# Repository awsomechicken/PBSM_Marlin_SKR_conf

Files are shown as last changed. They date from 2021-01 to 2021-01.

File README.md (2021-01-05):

# PBSM_Marlin_SKR_conf
Configuration to upgrade the Printrbot Simple Metal to an SKR Mini V1.2 controller.

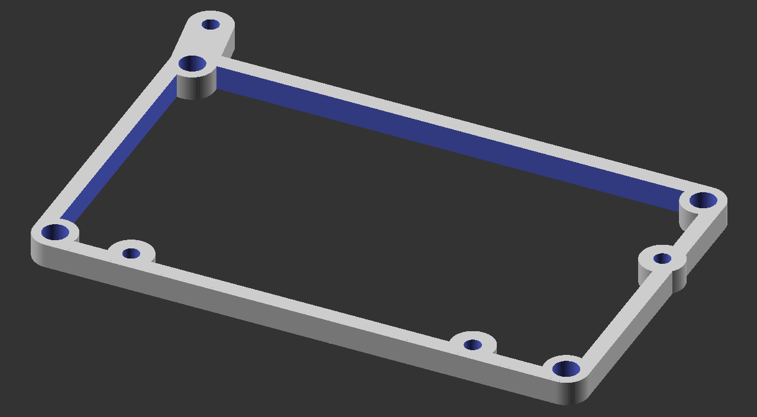
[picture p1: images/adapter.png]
Board mount

The board adapter (in its current form) needs 4x M3x5mm standoffs. to mount the board.

# Wiring:
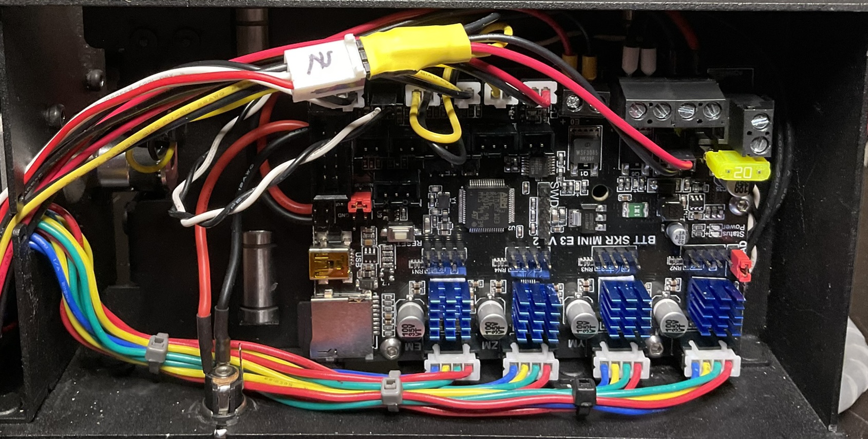
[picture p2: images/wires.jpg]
Wiring photo

#### Z-Probe voltage divider harness:
The inductive probe used for bed leveling, I've wired mine to run off the +12V tap on the board, with a 12k&Omega; voltage divider:

(Signal)----[9k&Omega;]----{Vout}----[3k&Omega;]----(GND)

Vout is the 3V signal from the signal output of the probe, wire this to the z-stop connector and __not__ the probe connector.

#### Motors:
I wired all the motors into JST connectors.

# Configuration Notes:
## Heaters:
#### Hotend:
PID settings for the Ubis hotend: `M301 P22.20 I1.08 D114.00`
#### Bed:
The Bed doesn't need PID control, due to the thermal mass of the bed and low wattage of the heater, so I have the "bang-bang" mode enabled.

## Bed Leveling:
Using bilinear mesh 7x7 (49pt), because my stock printrbot bent aluminum bed is rather warped (+/- .35mm).

## Motion Settings:
The Printrbot stock step/mm settings have just been copied over: `M92 X80.00 Y80.00 Z2020.00 E94.50`
with max feedrates:
`M203 X150.00 Y150.00 Z7.00 E40.00`
and maximum acceleration setting:
`M201 X2000.00 Y2000.00 Z100.00 E10000.00`
with acceleration set to:
`M204 P1500.00 R3000.00 T1500`

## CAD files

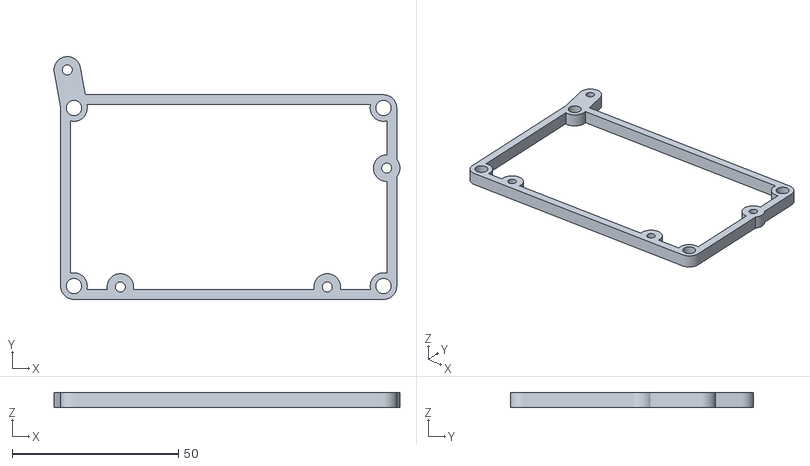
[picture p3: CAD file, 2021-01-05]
adapters/Printrbot_board_adapter.stl
104.0 x 73.0 x 4.50

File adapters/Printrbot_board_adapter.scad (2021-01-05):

// printrbot simple metal adapter to mount BTT SKR Mini controller

adapter();
//opz();
//keystone();

module adapter(){
  $fn=64;
  // printrboard mounting holes
  H = 4.5;
  bo=6; // board offset
  difference(){
    hull()for(i=[-.5:1:.5],j=[-.5:1:.5]) translate([93*i,53.5*j,0])
      cylinder(d=8,h=H);
    hull()for(i=[-.5:1:.5],j=[-.5:1:.5]) translate([93*i,53.5*j,-.5])
      cylinder(d=2,h=H+1);
    for(i=[-.5:1:.5],j=[-.5:1:.5]) translate([93*i,53.5*j,-.5])
      cylinder(d=4.6,h=H+1);
    translate([0,bo,-.5]) skrmini_footprint(D=3,H=H+1);
  }
  difference(){
    for(i=[-.5:1:.5],j=[-.5:1:.5]) translate([93*i,53.5*j,0])
      cylinder(d=8,h=H);
    for(i=[-.5:1:.5],j=[-.5:1:.5]) translate([93*i,53.5*j,-.5])
      cylinder(d=4.6,h=H+1);
  }
  translate([0,bo]) difference(){
    intersection(){
      union(){
        dd = 8;
        skrmini_footprint(D=dd,H=H);
        hull(){
          translate([-50+1.5,34.75-2.54]) cylinder(d=dd,h=H);
          translate([-46.5,21.25]) cylinder(d=dd,h=H);
        }
      }
      translate([0,4.25-.5,0]) cube([110,80,H+10],center=true);
    }
    translate([0,0,-.5]) skrmini_footprint(D=3,H=H+1);
    translate([93*-.5,21.25-.5,-.5]) cylinder(d=4.6,h=H+1);
  }//*/
}

module skrmini_footprint(D=3,H=4){
  //%cube([100,70.25,1],center=true);
  translate([50-(20.40),-35.125+2.12]) cylinder(d=D,h=H); // between xm and ym
  translate([(17.45)-50,-35.125+2.12]) cylinder(d=D,h=H); // behind the sd slot
  translate([-50+1.5,34.75-2.54]) cylinder(d=D,h=H);
  //translate([-50+1.5,34.75-2.54]) cylinder(d=D,h=H);
  translate([50-2.54,34.75-32.05]) cylinder(d=D,h=H);
}

module opz(){
  $fn=64;
  for(i=[-.5:1:.5],j=[-.5:1:.5]) translate([63*i,42*j,0]) difference(){
    cylinder(d=6,h=5.5,center=true);
    cylinder(d=3,h=6,center=true);
  }
  translate([0,0,-1.75]) difference(){
    cube([66,45,2],center=true);
    cube([61,40,4],center=true);
    for(i=[-.5:1:.5],j=[-.5:1:.5]) translate([63*i,42*j,0]) cylinder(d=3,h=6,center=true);
    for(i=[-.5:1:.5],j=[-.5:1:.5]) translate([52*i,31*j,.5]) cylinder(d=8,h=3.1,center=true);
  }
  translate([0,0,-1.75]) difference(){
    cube([50,32,2],center=true);
    cube([45,27,4],center=true);
    for(i=[-.5:1:.5],j=[-.5:1:.5]) translate([63*i,42*j,0]) cylinder(d=3,h=6,center=true);
    for(i=[-.5:1:.5],j=[-.5:1:.5]) translate([52*i,31*j,.5]) cylinder(d=8,h=3.1,center=true);
  }
  difference(){
    for(i=[-.5:1:.5],j=[-.5:1:.5]) translate([52*i,31*j,-1.25])
      cylinder(d=14,h=3,center=true);
    #for(i=[-.5:1:.5],j=[-.5:1:.5]) translate([63*i,42*j,-1.75])
      cylinder(d=3,h=6,center=true);
    #for(i=[-.5:1:.5],j=[-.5:1:.5]) translate([52*i,31*j,-1.25])
      cylinder(d=8,h=3.1,center=true);

  }

}

module keystone(){
  $fn=64;
  difference(){
    union(){
      hull() for(i=[-.5:1:.5],j=[-.5:1:.5])
        translate([36*i-19,20*j,-9.5]) cylinder(d=12,h=3);
      hull() for(j=[-.5:1:.5])
        translate([15-16,20*j,-9.5]) cylinder(d=12,h=19+3);
      translate([-39,0,-3.25-.5]) cube([8,12,9.5+2],center=true); // cable mount
    }
    translate([0,0,3]) union(){// keystone body
      cube([10+1,16+1,14.5+1],center=true); // keystone head
      translate([-10,1.5,0]) cube([20,19.75,13+1.5+1],center=true);
      translate([-1,2,0]) cube([4,23,13+1.5+1],center=true); // catch
      translate([-15-2,0,.25]) cube([20+4,22.5+1,19+.5],center=true); // cable termination block
    }
    for(i=[-.5:1:.5],j=[-.5:1:.5])
      translate([36*i-19,20*j,-9.5-.25]) cylinder(d=8,h=3.51);
    for(i=[-.5:1:.5],j=[-.5:1:.5])
      translate([36*i-19,20*j,-9.5+3.25]) cylinder(d1=8,d2=2,h=4,$fn=64);

    translate([-39,0,-5.5]) cube([3.5,20,2],center=true);
    translate([-39,0,3]) rotate([0,90,0]) cylinder(d=7,h=10,center=true);
  }
}

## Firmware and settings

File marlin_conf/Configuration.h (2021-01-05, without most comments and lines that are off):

#pragma once
#define CONFIGURATION_H_VERSION 020007
#define STRING_CONFIG_H_AUTHOR "awsomechicken (R. Sanford)" // Who made the changes.
#define SERIAL_PORT 2
#define SERIAL_PORT_2 -1
#define BAUDRATE 115200
  #define MOTHERBOARD BOARD_BTT_SKR_MINI_E3_V1_2
#define CUSTOM_MACHINE_NAME "Printrbot Simple Metal"
#define EXTRUDERS 1
#define DEFAULT_NOMINAL_FILAMENT_DIA 1.75
#define TEMP_SENSOR_0 1
#define TEMP_SENSOR_1 0
#define TEMP_SENSOR_2 0
#define TEMP_SENSOR_3 0
#define TEMP_SENSOR_4 0
#define TEMP_SENSOR_5 0
#define TEMP_SENSOR_6 0
#define TEMP_SENSOR_7 0
#define TEMP_SENSOR_BED 1 // Printrbot heated bed change to 1 to enable
#define TEMP_SENSOR_PROBE 0
#define TEMP_SENSOR_CHAMBER 0
#define DUMMY_THERMISTOR_998_VALUE 25
#define DUMMY_THERMISTOR_999_VALUE 100
#define MAX_REDUNDANT_TEMP_SENSOR_DIFF 10
#define TEMP_RESIDENCY_TIME     10  // (seconds) Time to wait for hotend to "settle" in M109
#define TEMP_WINDOW              1  // (°C) Temperature proximity for the "temperature reached" timer
#define TEMP_HYSTERESIS          3  // (°C) Temperature proximity considered "close enough" to the target
#define TEMP_BED_RESIDENCY_TIME 10  // (seconds) Time to wait for bed to "settle" in M190
#define TEMP_BED_WINDOW          1  // (°C) Temperature proximity for the "temperature reached" timer
#define TEMP_BED_HYSTERESIS      3  // (°C) Temperature proximity considered "close enough" to the target
#define HEATER_0_MINTEMP   5
#define HEATER_1_MINTEMP   5
#define HEATER_2_MINTEMP   5
#define HEATER_3_MINTEMP   5
#define HEATER_4_MINTEMP   5
#define HEATER_5_MINTEMP   5
#define HEATER_6_MINTEMP   5
#define HEATER_7_MINTEMP   5
#define BED_MINTEMP        5
#define HEATER_0_MAXTEMP 275
#define HEATER_1_MAXTEMP 275
#define HEATER_2_MAXTEMP 275
#define HEATER_3_MAXTEMP 275
#define HEATER_4_MAXTEMP 275
#define HEATER_5_MAXTEMP 275
#define HEATER_6_MAXTEMP 275
#define HEATER_7_MAXTEMP 275
#define BED_MAXTEMP      110
#define PIDTEMP
#define BANG_MAX 255     // Limits current to nozzle while in bang-bang mode; 255=full current
#define PID_MAX BANG_MAX // Limits current to nozzle while PID is active (see PID_FUNCTIONAL_RANGE below); 255=full current
#define PID_K1 0.95      // Smoothing factor within any PID loop
    #define DEFAULT_Kp  37.61
    #define DEFAULT_Ki   6.26
    #define DEFAULT_Kd  56.54
#define MAX_BED_POWER 255 // limits duty cycle to bed; 255=full current
  #define PID_FUNCTIONAL_RANGE 10 // If the temperature difference between the target temperature and the actual temperature
#define PREVENT_COLD_EXTRUSION
#define EXTRUDE_MINTEMP 170
#define PREVENT_LENGTHY_EXTRUDE
#define EXTRUDE_MAXLENGTH 200
#define THERMAL_PROTECTION_HOTENDS // Enable thermal protection for all extruders
#define THERMAL_PROTECTION_BED     // Enable thermal protection for the heated bed
#define USE_XMIN_PLUG
#define USE_ZMIN_PLUG
#define USE_YMAX_PLUG
#define ENDSTOPPULLUPS
#define X_MIN_ENDSTOP_INVERTING false // Set to true to invert the logic of the endstop.
#define Y_MIN_ENDSTOP_INVERTING false // Set to true to invert the logic of the endstop.
#define Z_MIN_ENDSTOP_INVERTING false // Set to true to invert the logic of the endstop.
#define X_MAX_ENDSTOP_INVERTING false // Set to true to invert the logic of the endstop.
#define Y_MAX_ENDSTOP_INVERTING false // Set to true to invert the logic of the endstop.
#define Z_MAX_ENDSTOP_INVERTING false // Set to true to invert the logic of the endstop.
#define Z_MIN_PROBE_ENDSTOP_INVERTING false // Set to true to invert the logic of the probe.
#define X_DRIVER_TYPE  TMC2209
#define Y_DRIVER_TYPE  TMC2209
#define Z_DRIVER_TYPE  TMC2209
#define E0_DRIVER_TYPE TMC2209
#define DEFAULT_AXIS_STEPS_PER_UNIT   { 80, 80, 2020, 94.5 } // if acme rod change Z to 400
#define DEFAULT_MAX_FEEDRATE          { 150, 150, 7, 40 }
#define DEFAULT_MAX_ACCELERATION      { 2000, 2000, 100, 10000 }
#define DEFAULT_ACCELERATION          1500    // X, Y, Z and E acceleration for printing moves
#define DEFAULT_RETRACT_ACCELERATION  3000    // E acceleration for retracts
#define DEFAULT_TRAVEL_ACCELERATION   1500    // X, Y, Z acceleration for travel (non printing) moves
#define DEFAULT_EJERK    5.0  // May be used by Linear Advance
  #define JUNCTION_DEVIATION_MM 0.013 // (mm) Distance from real junction edge
  #define JD_HANDLE_SMALL_SEGMENTS    // Use curvature estimation instead of just the junction angle
#define S_CURVE_ACCELERATION
#define Z_MIN_PROBE_USES_Z_MIN_ENDSTOP_PIN
#define FIX_MOUNTED_PROBE
#define NOZZLE_TO_PROBE_OFFSET { 20, 0, 0 }
#define PROBING_MARGIN 10
#define XY_PROBE_SPEED (25*60)
#define Z_PROBE_SPEED_FAST (4*60)
#define Z_PROBE_SPEED_SLOW (Z_PROBE_SPEED_FAST / 2)
#define MULTIPLE_PROBING 3
#define Z_CLEARANCE_DEPLOY_PROBE    4 // Z Clearance for Deploy/Stow
#define Z_CLEARANCE_BETWEEN_PROBES  3 // Z Clearance between probe points
#define Z_CLEARANCE_MULTI_PROBE     3 // Z Clearance between multiple probes
#define Z_PROBE_LOW_POINT          -2 // Farthest distance below the trigger-point to go before stopping
#define Z_PROBE_OFFSET_RANGE_MIN -2
#define Z_PROBE_OFFSET_RANGE_MAX 20
#define X_ENABLE_ON 0
#define Y_ENABLE_ON 0
#define Z_ENABLE_ON 0
#define E_ENABLE_ON 0 // For all extruders
#define DISABLE_X false
#define DISABLE_Y false
#define DISABLE_Z false
#define DISABLE_E false             // Disable the extruder when not stepping
#define DISABLE_INACTIVE_EXTRUDER   // Keep only the active extruder enabled
#define INVERT_X_DIR false
#define INVERT_Y_DIR true
#define INVERT_Z_DIR false
#define INVERT_E0_DIR false
#define INVERT_E1_DIR false
#define INVERT_E2_DIR false
#define INVERT_E3_DIR false
#define INVERT_E4_DIR false
#define INVERT_E5_DIR false
#define INVERT_E6_DIR false
#define INVERT_E7_DIR false
#define Z_HOMING_HEIGHT  5        // (mm) Minimal Z height before homing (G28) for Z clearance above the bed, clamps, ...
#define X_HOME_DIR -1
#define Y_HOME_DIR 1
#define Z_HOME_DIR -1
#define X_BED_SIZE 152
#define Y_BED_SIZE 152
#define X_MIN_POS 0
#define Y_MIN_POS 0
#define Z_MIN_POS 0
#define X_MAX_POS X_BED_SIZE
#define Y_MAX_POS Y_BED_SIZE
#define Z_MAX_POS 205
#define MIN_SOFTWARE_ENDSTOPS
  #define MIN_SOFTWARE_ENDSTOP_X
  #define MIN_SOFTWARE_ENDSTOP_Y
  #define MIN_SOFTWARE_ENDSTOP_Z
#define MAX_SOFTWARE_ENDSTOPS
  #define MAX_SOFTWARE_ENDSTOP_X
  #define MAX_SOFTWARE_ENDSTOP_Y
  #define MAX_SOFTWARE_ENDSTOP_Z
#define AUTO_BED_LEVELING_BILINEAR
#define RESTORE_LEVELING_AFTER_G28
  #define ENABLE_LEVELING_FADE_HEIGHT
    #define DEFAULT_LEVELING_FADE_HEIGHT 10.0 // (mm) Default fade height.
  #define SEGMENT_LEVELED_MOVES
  #define LEVELED_SEGMENT_LENGTH 10.0 // (mm) Length of all segments (except the last one)
  #define GRID_MAX_POINTS_X 7
  #define GRID_MAX_POINTS_Y GRID_MAX_POINTS_X
#define Z_SAFE_HOMING
  #define Z_SAFE_HOMING_X_POINT X_CENTER  // X point for Z homing
  #define Z_SAFE_HOMING_Y_POINT Y_CENTER  // Y point for Z homing
#define HOMING_FEEDRATE_XY (25*60)
#define HOMING_FEEDRATE_Z (4*60)
#define VALIDATE_HOMING_ENDSTOPS
#define EEPROM_SETTINGS     // Persistent storage with M500 and M501
#define EEPROM_CHITCHAT       // Give feedback on EEPROM commands. Disable to save PROGMEM.
#define EEPROM_BOOT_SILENT    // Keep M503 quiet and only give errors during first load
#define HOST_KEEPALIVE_FEATURE        // Disable this if your host doesn't like keepalive messages
#define DEFAULT_KEEPALIVE_INTERVAL 2  // Number of seconds between "busy" messages. Set with M113.
#define BUSY_WHILE_HEATING            // Some hosts require "busy" messages even during heating
#define PREHEAT_1_LABEL       "PLA"
#define PREHEAT_1_TEMP_HOTEND 180
#define PREHEAT_1_TEMP_BED     45
#define PREHEAT_1_FAN_SPEED     0 // Value from 0 to 255
#define PREHEAT_2_LABEL       "ABS"
#define PREHEAT_2_TEMP_HOTEND 240
#define PREHEAT_2_TEMP_BED    80
#define PREHEAT_2_FAN_SPEED     0 // Value from 0 to 255
#define PRINTJOB_TIMER_AUTOSTART
#define LCD_LANGUAGE en
#define DISPLAY_CHARSET_HD44780 JAPANESE
#define SDSUPPORT
#define FAN_SOFT_PWM
#define SOFT_PWM_SCALE 0
#define SERVO_DELAY { 300 }

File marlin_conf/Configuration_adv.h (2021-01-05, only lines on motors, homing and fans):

#define E0_AUTO_FAN_PIN -1
#define E1_AUTO_FAN_PIN -1
#define E2_AUTO_FAN_PIN -1
#define E3_AUTO_FAN_PIN -1
#define E4_AUTO_FAN_PIN -1
#define E5_AUTO_FAN_PIN -1
#define E6_AUTO_FAN_PIN -1
#define E7_AUTO_FAN_PIN -1
#define CHAMBER_AUTO_FAN_PIN -1
#define HOMING_BUMP_MM      { 5, 5, 2 }       // (mm) Backoff from endstops after first bump
#define HOMING_BUMP_DIVISOR { 2, 2, 4 }       // Re-Bump Speed Divisor (Divides the Homing Feedrate)
#define MICROSTEP_MODES { 16, 16, 16, 16, 16, 16 } // [1,2,4,8,16]
    #define X_CURRENT       800        // (mA) RMS current. Multiply by 1.414 for peak current.
    #define X_CURRENT_HOME  X_CURRENT  // (mA) RMS current for sensorless homing
    #define X_MICROSTEPS     16    // 0..256
    #define Y_CURRENT       800
    #define Y_CURRENT_HOME  Y_CURRENT
    #define Y_MICROSTEPS     16
    #define Z_CURRENT       800
    #define Z_CURRENT_HOME  Z_CURRENT
    #define Z_MICROSTEPS     16
    #define E0_CURRENT      800
    #define E0_MICROSTEPS    16
  #define X_HYBRID_THRESHOLD     100  // [mm/s]
  #define X2_HYBRID_THRESHOLD    100
  #define Y_HYBRID_THRESHOLD     100
  #define Y2_HYBRID_THRESHOLD    100
  #define Z_HYBRID_THRESHOLD       3
  #define Z2_HYBRID_THRESHOLD      3
  #define Z3_HYBRID_THRESHOLD      3
  #define Z4_HYBRID_THRESHOLD      3
  #define E0_HYBRID_THRESHOLD     30
  #define E1_HYBRID_THRESHOLD     30
  #define E2_HYBRID_THRESHOLD     30
  #define E3_HYBRID_THRESHOLD     30
  #define E4_HYBRID_THRESHOLD     30
  #define E5_HYBRID_THRESHOLD     30
  #define E6_HYBRID_THRESHOLD     30
  #define E7_HYBRID_THRESHOLD     30

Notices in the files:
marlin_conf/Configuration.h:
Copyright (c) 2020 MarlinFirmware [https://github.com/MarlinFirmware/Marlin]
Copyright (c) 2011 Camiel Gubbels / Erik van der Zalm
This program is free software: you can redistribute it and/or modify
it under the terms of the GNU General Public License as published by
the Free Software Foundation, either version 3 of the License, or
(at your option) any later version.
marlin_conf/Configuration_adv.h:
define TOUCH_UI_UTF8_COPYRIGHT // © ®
